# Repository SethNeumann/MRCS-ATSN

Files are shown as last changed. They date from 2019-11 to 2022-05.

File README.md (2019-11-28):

# MRCS-ATSN
### License: Creative Commons Attribution-NonCommercial-ShareAlike

## Dispatcher/Operator Telephone board / Electronic Speech Telephone Network board (ASTN)

(Designed by MRCS)

The Electronic Speech Telephone Network (ASTN) board provides the
electronics and connections for building a telephone for a Dispatcher
or Operator for use with a model railroad telephone system using
either a microphone/speaker/footswitch arrangement or using an
inexpensive computer headset.  The Mic/Speaker/Foot switch arrangement
is recommended where the dispatcher or operator will be in a
sound-isolated environment and the headset (preferably noise
cancelling) is recommended for Operators and Dispatchers who will
be in the layout room.  Features include:

  * Supports either Dynamic or Electret microphones
  * Independent control of outbound, inbound and "break-in" volume
  * Break in volume is the level heard by the user when depressing the footswitch (prototype train order operators would break in if there was an error during an order or repeat as a safety measure)
  * Can be used to "modernize" a classic candlestick type phone for better performance in a noisy layout room
  * supports mono or stereo inputs and outputs
  * optional phase reversal on output to help tune maximum volume without feedback
  * No DC load on the dispatcher's line
  * line level output for powered speakers or input to an external amplifier
  * uses 24 VDC
  * optional remote volume controls
  * transmit LED indicator

This is a Model Railroad Control Systems Telephony design by Clint Gilliland,
Seth Neumann and John Plocher.

You are free to download the files and make your own or you can
purchase bare boards or assembled and tested product from
[Model Railroad Control Systems](http://www.modelrailroadcontrolsystems.com/).

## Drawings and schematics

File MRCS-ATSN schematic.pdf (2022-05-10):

# 22K ¹⁵K

# R13 R⁹

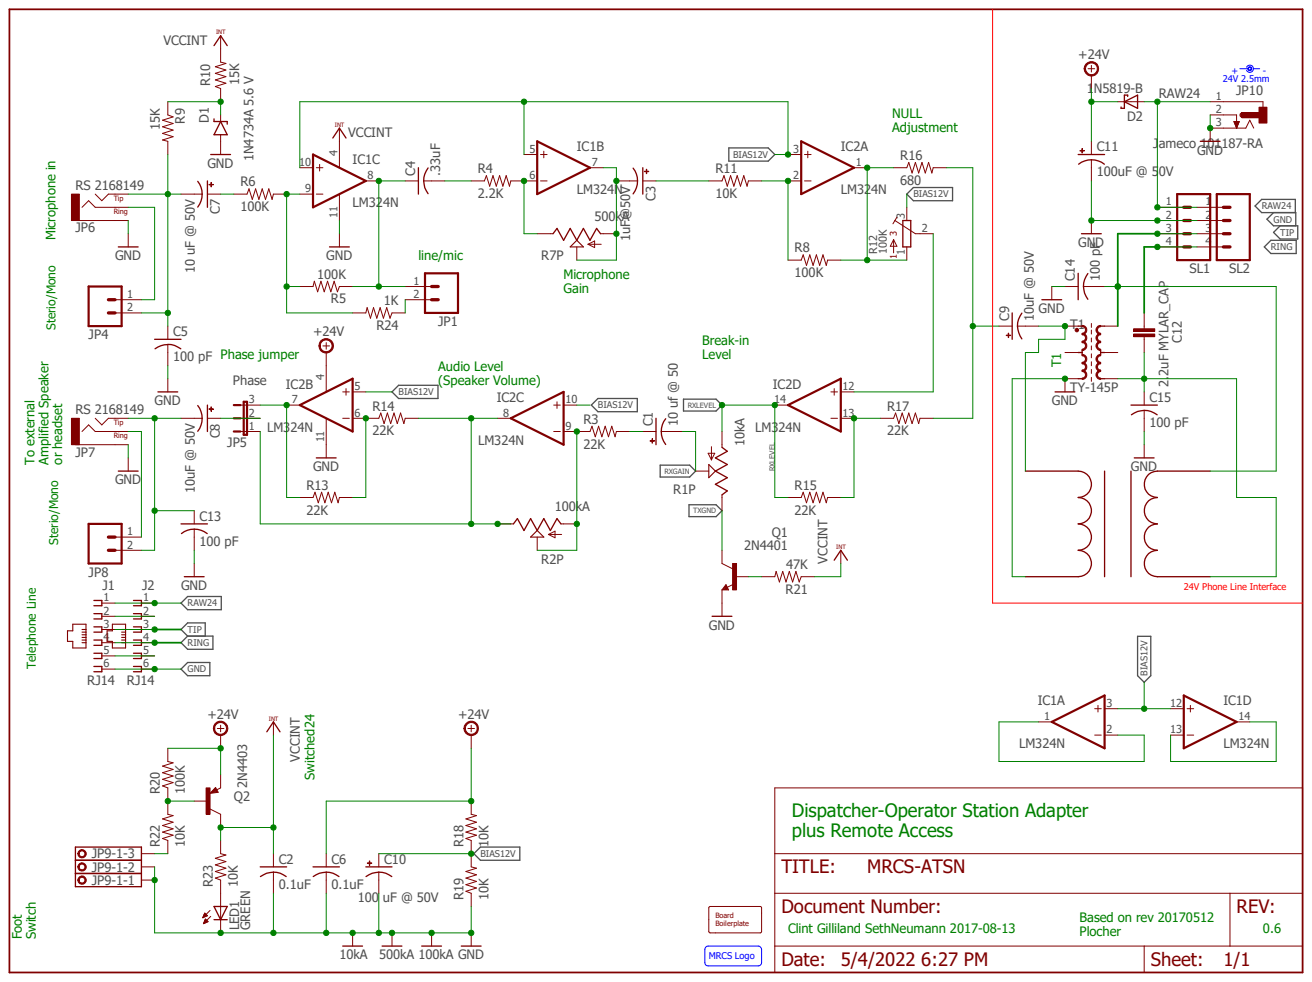
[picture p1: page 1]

Clint Gilliland SethNeumann 2017-08-13 To external Amplified Speaker or headset Microphone in Foot Switch

Level Sterio/Mono Sterio/Mono Telephone Line

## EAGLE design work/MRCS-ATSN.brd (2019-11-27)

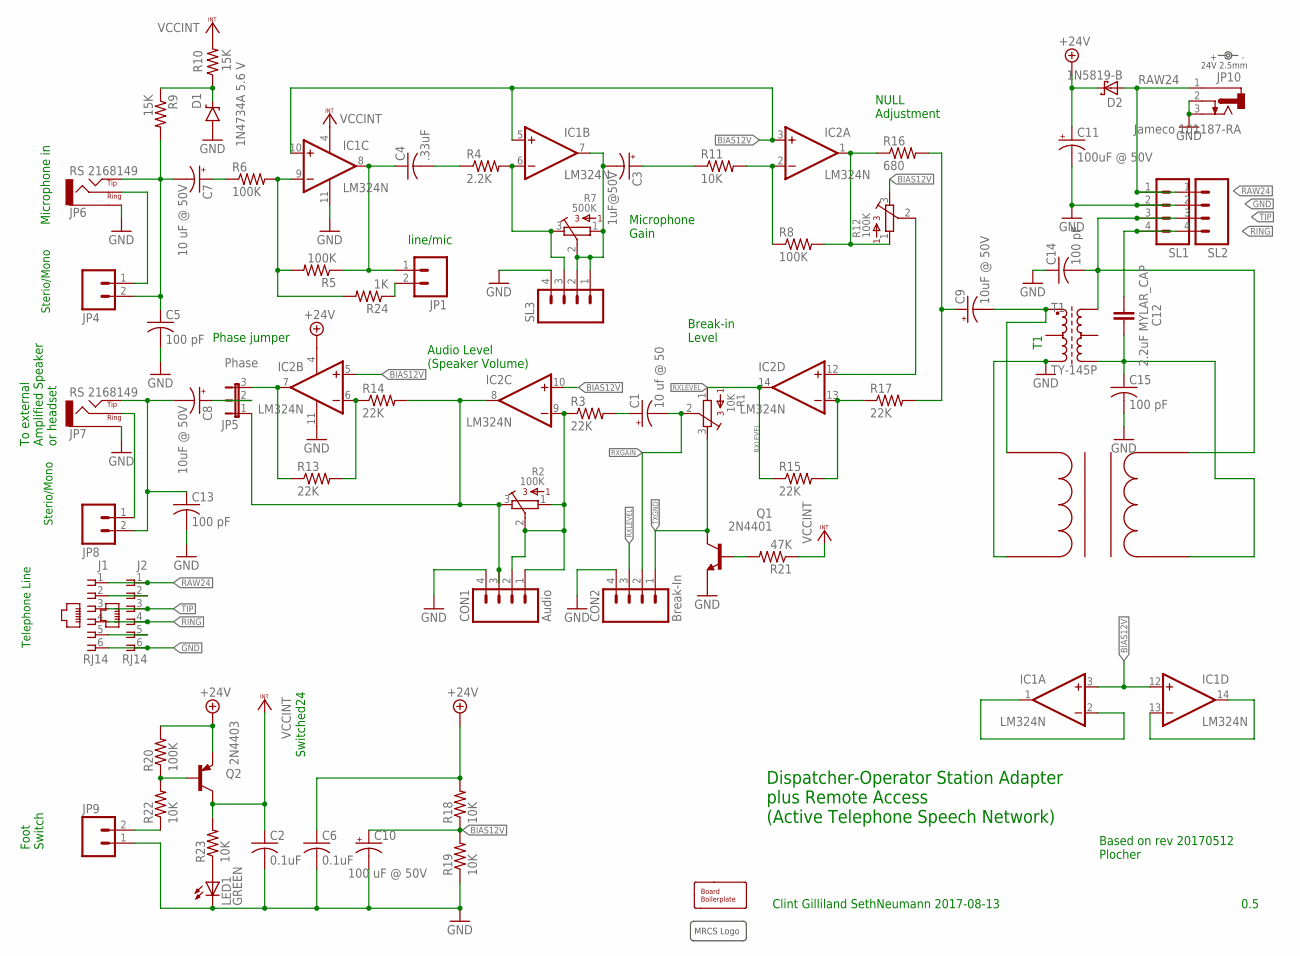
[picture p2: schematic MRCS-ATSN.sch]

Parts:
BOARD1: BOARD69X100; BOARD-DINRAIL-2.7IN-16CM
C1: 10 uf @ 50; E2-5
C2, C6: 0.1uF; C025-030X050
C3: 1uF@50V; E2-5
C4: .33uF; C050-050X075
C5, C13: 100 pF; C050-025X075
C7: 10 uF @ 50V; E2-5
C8, C9: 10uF @ 50V; E2-5
C10: 100 uF @ 50V; E3.5-10
C11: 100uF @ 50V; E3.5-10
C12: 2.2uF MYLAR_CAP; C15B9
C14, C15: 100 pF; C025-030X050
CON1: Audio; 1X04_LOCK
CON2: Break-In; 1X04_LOCK
D1: 1N4734A 5.6 V; DIODE-ZENER
D2: 1N5819-B; DO41-7.6
IC1, IC2: LM324N; DIL14
J1, J2: RJ14; RJ25-INVERTED
JP1, JP4, JP8: CONNECTOR-M021X02-LOCK; 1X02_LOCK
JP5: Phase; 1X03
JP6, JP7: RS 2168149; AUDIO-JACK-3.5MM_STEREO
JP9: CONNECTOR-M02508-LOCK; MSTB2
JP10: Jameco 101187-RA; DCJ0202
LED1: GREEN; LED3MM
POWER: 24V 2.5mm; POWER_USAGE
Q1: 2N4401; TO92-EBC
Q2: 2N4403; TO92-CBE
R1: 10K; 3386K
R2, R12: 100K; 3386K
R3, R13, R14, R15, R17: 22K; AXIAL-0.4
R4: 2.2K; AXIAL-0.4
R5, R6, R8, R20: 100K; AXIAL-0.4
R7: 500K; 3386K
R9, R10: 15K; AXIAL-0.4
R11, R18, R19, R22, R23: 10K; AXIAL-0.4
R16: 680; AXIAL-0.4
R21: 47K; AXIAL-0.4
R24: 1K; AXIAL-0.4
SL1, SL2, SL3: CONNECTOR-M04POLAR_LOCK; MOLEX-1X4_LOCK
T1: TY-145P; TRANFORMER
U$1: MRCS-LOGOBOT-LARGE; MRCS-LOGO
U$2: EI14_600-600; XFMR580X500

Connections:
+24V: C6.1, C11.+, D2.C, IC2.4 (V+), Q2.E, R18.P$2 (2), R20.P$2 (2)
BIAS12V: C10.+, IC1.5 (+IN), IC1.10 (+IN), IC2.3 (+IN), IC2.5 (+IN), IC2.10 (+IN), R12.3, R18.P$1 (1), R19.P$2 (2)
GND: C2.2, C5.2, C6.2, C10.-, C11.-, C13.2, C14.1, C15.2, CON1.4, CON2.4, D1.P$2 (A), IC1.11 (V-), IC2.11 (V-), J1.6, J2.6, JP6.GND (SLEEVE), JP7.GND (SLEEVE), JP9.1, JP10.2, JP10.3, LED1.K (C), Q1.E, R19.P$1 (1), SL1.2, SL2.2, SL3.4, T1.3 (E1), U$2.PBOTTOM
MICPOWER: D1.P$1 (C), R9.P$1 (1), R10.P$1 (1)
MICRING: JP4.1, JP6.RING
MICTIP: C5.1, C7.-, JP4.2, JP6.TIP, R9.P$2 (2)
unnamed: C7.+, R6.P$1 (1)
unnamed: IC1.1 (OUT), IC1.2 (-IN)
unnamed: JP1.2, R24.P$1 (1)
unnamed: IC1.3 (+IN), IC1.12 (+IN)
unnamed: Q2.B, R20.P$1 (1), R22.P$2 (2)
unnamed: IC1.9 (-IN), R5.P$2 (2), R6.P$2 (2), R24.P$2 (2)
unnamed: J1.2, J2.2
unnamed: C1.+, R3.P$2 (2)
unnamed: IC2.13 (-IN), R15.P$2 (2), R17.P$1 (1)
unnamed: J1.5, J2.5
unnamed: C3.-, IC1.7 (OUT), R7.1, R7.2, SL3.1, SL3.2
unnamed: IC2.2 (-IN), R8.P$1 (1), R11.P$2 (2)
unnamed: IC2.1 (OUT), R8.P$2 (2), R12.1, R16.P$1 (1)
unnamed: JP9.2, R22.P$1 (1)
unnamed: C3.+, R11.P$1 (1)
unnamed: C4.1, IC1.8 (OUT), JP1.1, R5.P$1 (1)
unnamed: CON1.1, CON1.2, IC2.9 (-IN), R2.1, R2.2, R3.P$1 (1)
unnamed: LED1.A, R23.P$1 (1)
unnamed: IC2.12 (+IN), R12.2
unnamed: IC1.13 (-IN), IC1.14 (OUT)
unnamed: C8.+, JP5.2
unnamed: IC1.6 (-IN), R4.P$2 (2), R7.3, SL3.3
unnamed: C4.2, R4.P$1 (1)
unnamed: CON1.3, IC2.8 (OUT), JP5.1, R2.3, R14.P$2 (2)
unnamed: IC2.7 (OUT), JP5.3, R13.P$1 (1)
unnamed: IC2.6 (-IN), R13.P$2 (2), R14.P$1 (1)
Q1BASE: Q1.B, R21.P$2 (2)
RAW24: D2.A, J1.1, J2.1, JP10.1, SL1.1, SL2.1
RING: C12.2, J1.4, J2.4, SL1.4, SL2.4
RING-ISOLATED: C12.1, C15.1, T1.4 (E2), U$2.SBOTTOM
RXGAIN: C1.-, CON2.2, R1.2
RXLEVEL: CON2.3, IC2.14 (OUT), R1.1, R15.P$1 (1)
SPKRRING: JP7.RING, JP8.1
SPKRTIP: C8.-, C13.1, JP7.TIP, JP8.2
TELCO-IN: C9.-, T1.1 (A1), U$2.PTOP
TELCO-IN-ISOLATED: C9.+, R16.P$2 (2), R17.P$2 (2)
TIP: C14.2, J1.3, J2.3, SL1.3, SL2.3, T1.6 (A2), U$2.STOP
TXGND: CON2.1, Q1.C, R1.3
VCCINT: C2.1, IC1.4 (V+), Q2.C, R10.P$2 (2), R21.P$1 (1), R23.P$2 (2)

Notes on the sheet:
Dispatcher-Operator Station Adapter plus Remote Access (Active Telephone Speech Network)
Clint Gilliland SethNeumann 2017-08-13
To external Amplified Speaker or headset
Microphone in
Foot Switch
NULL Adjustment
Microphone Gain
Phase jumper
Break-in Level
Sterio/Mono
Telephone Line
Based on rev 20170512 Plocher
Switched24
Audio Level (Speaker Volume)
0.5
line/mic

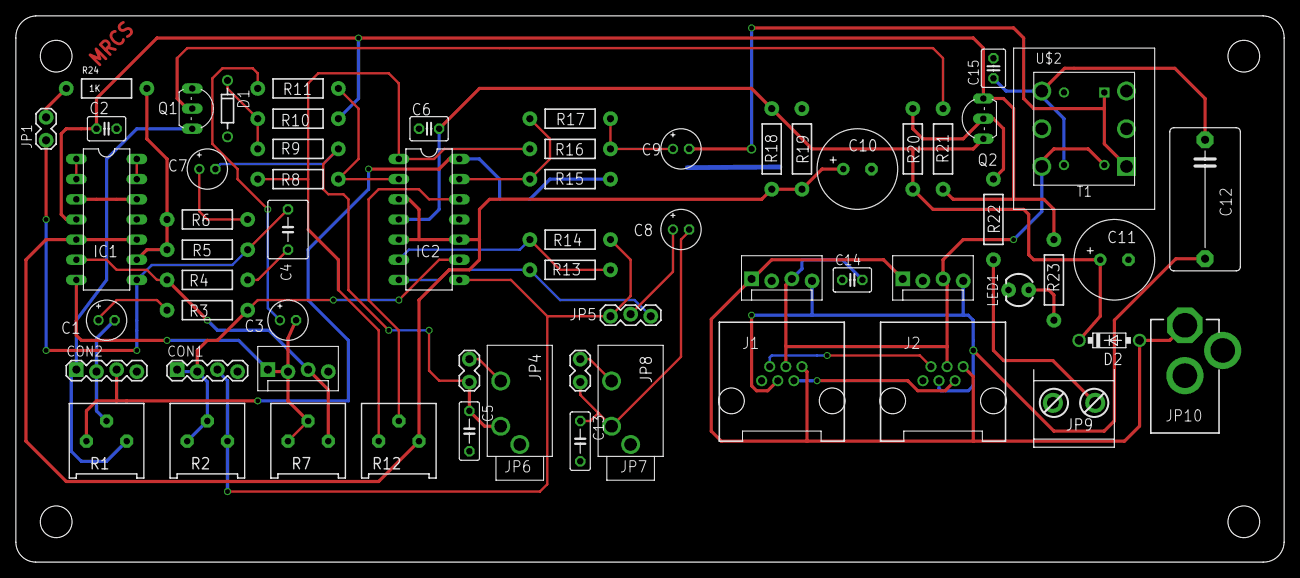
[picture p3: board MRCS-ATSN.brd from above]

Board: 2 copper layers, 159.8 x 68.8 mm, 66 parts (0 on the bottom side), 45 nets.

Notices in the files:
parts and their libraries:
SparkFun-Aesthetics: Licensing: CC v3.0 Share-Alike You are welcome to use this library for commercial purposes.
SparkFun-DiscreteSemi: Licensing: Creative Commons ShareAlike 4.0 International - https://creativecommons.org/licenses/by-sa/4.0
